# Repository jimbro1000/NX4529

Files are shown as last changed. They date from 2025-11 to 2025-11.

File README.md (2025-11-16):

# MC14529 Replacement #

This repository contains the design for a CPLD based
replacement for the long obsolete MC14529 analog
multiplexer. The design is intended only to act as a
substitute in the Dragon 32/64 computers.

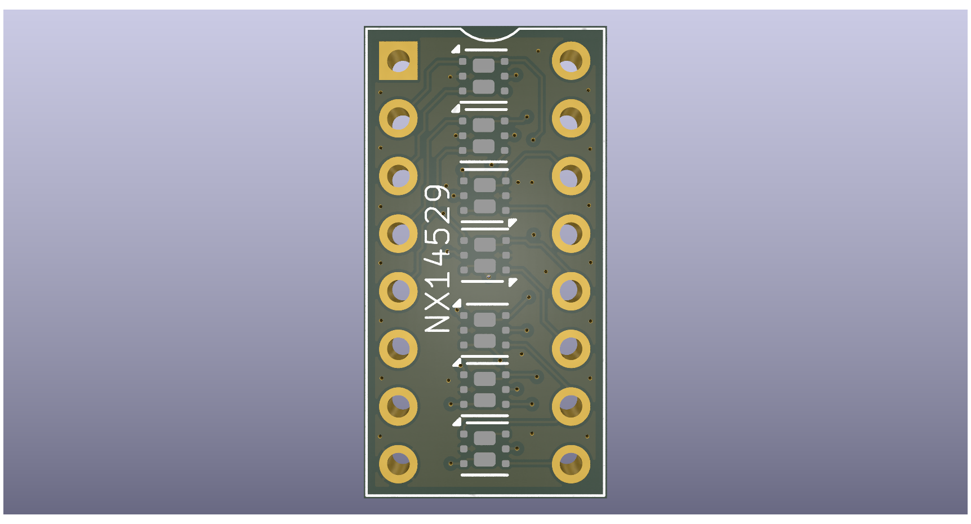
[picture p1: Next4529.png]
render of pcb


## Limitations ##

The original MC14529 can act a 8:1 multiplexer which ties
the two output pins together. It can also place the two
output pins in a high impedance state.

In both cases these configurations are limited in this 
design to suit the specific use-case for the Dragon.

1. The high impedance state is not implemented
2. The two output pins are only correct when the X
inputs are selected, if the Y inputs are selected the 
result will still be two independant outputs

## Design ##

The design is based around the Renesas SLG46824 CPLD.
This is a 3mm x 2mm device (about the size of a 1/4W
leaded resistor). The CPLD reproduces the truth table
of the original device.

The actual multiplexing is performed by an array of
LS74LVC1G3157 analog SPDT switches. These are available
in very small packages allowing seven of them to be
fitted in the available space.

The board design must retain the footprint of a DIP-16
device and provides the most significant design constraint.

## License ##

This project is licensed under creative commons CC-BY-SA 4.0

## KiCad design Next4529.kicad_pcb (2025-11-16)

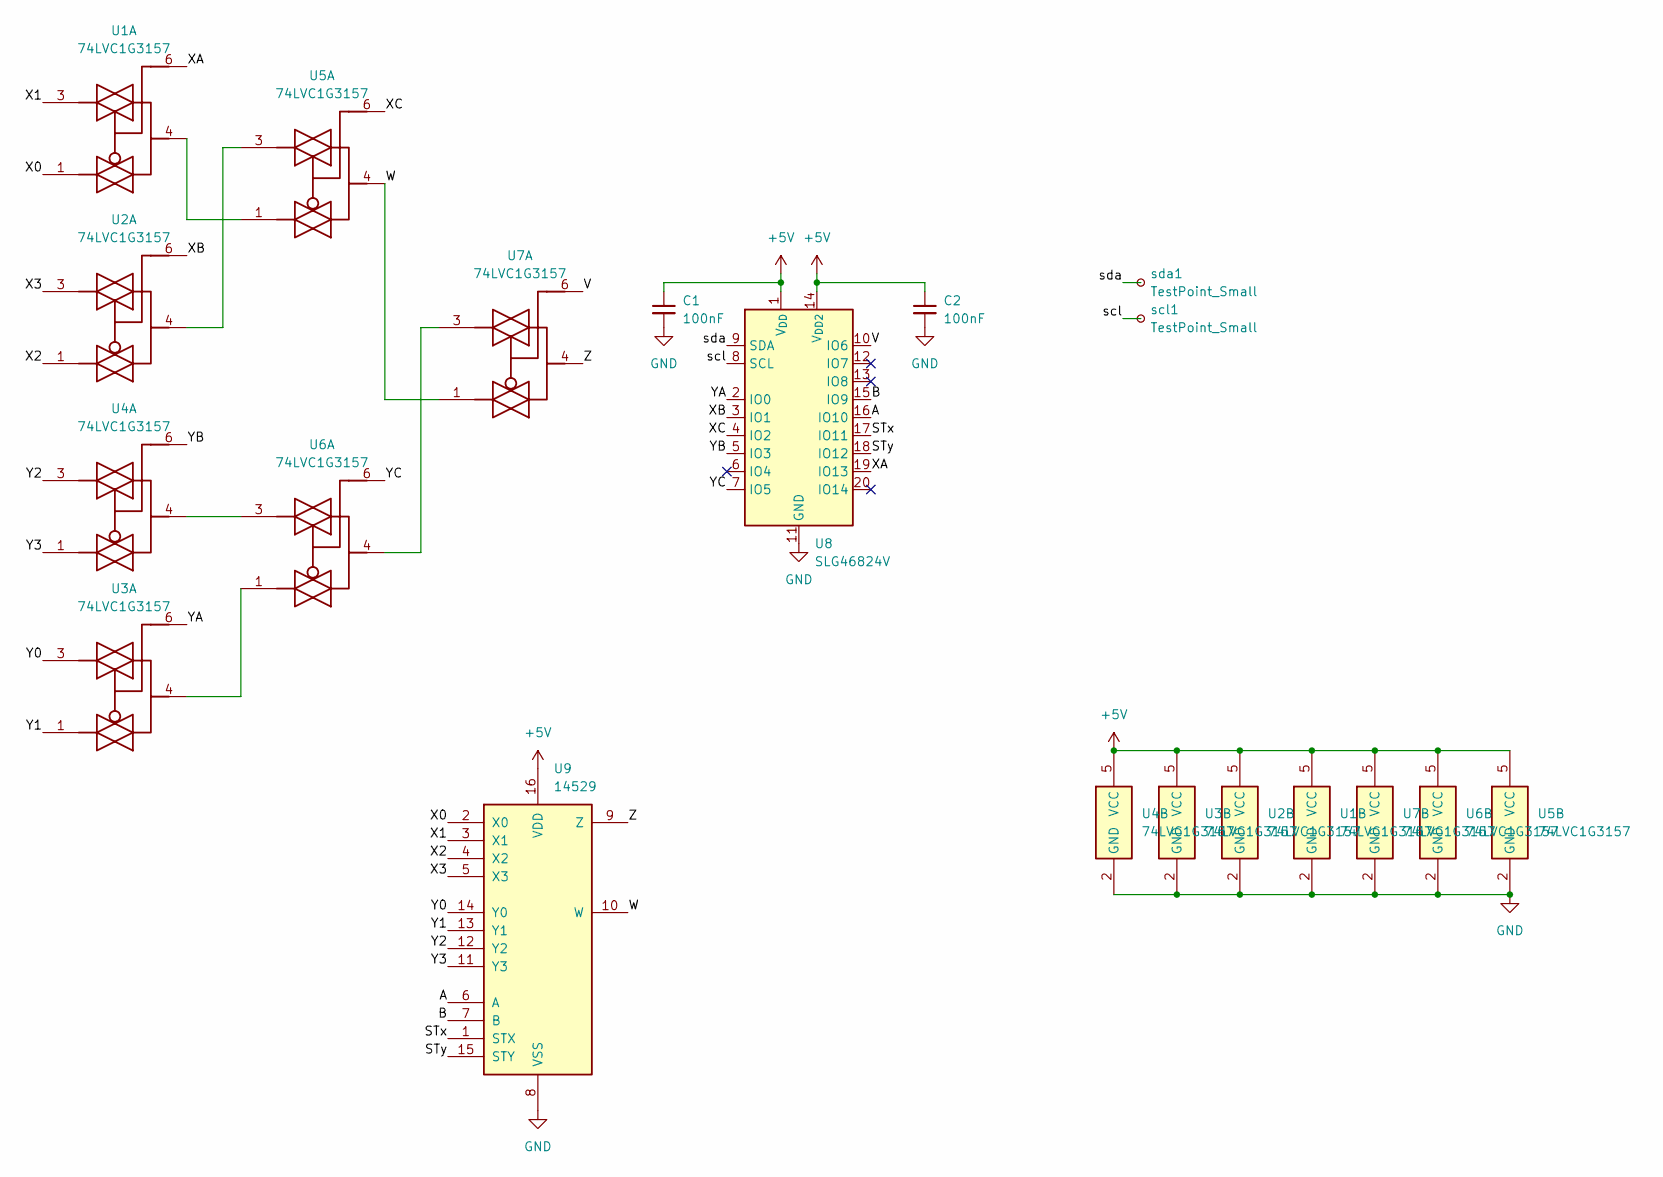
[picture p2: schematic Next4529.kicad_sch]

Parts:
C1, C2: 100nF; C_0402_1005Metric; DigiKey 1276-CL05B104KP5VPNCCT-ND
U1, U2, U3, U4, U5, U6, U7: 74LVC1G3157; Vishay_PowerPAK_SC70-6L_Dual; DigiKey 296-14909-1-ND
U8: SLG46824V; Renesas_UQFN-20_2x3mm_P0.4mm_LayoutBorder4x6y; DigiKey 1695-SLG46824VCT-ND
U9: 14529; DIP-16_board
scl1: TestPoint_Small; TestPoint_Pad_D1.0mm
sda1: TestPoint_Small; TestPoint_Pad_D1.0mm

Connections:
+5V: C1.1, C2.1, U1.5 (VCC), U2.5 (VCC), U3.5 (VCC), U4.5 (VCC), U5.5 (VCC), U6.5 (VCC), U7.5 (VCC), U8.1 (V_{DD}), U8.14 (V_{DD2}), U9.16 (VDD)
/A: U8.16 (IO10), U9.6 (A)
/B: U8.15 (IO9), U9.7 (B)
/STx: U8.17 (IO11), U9.1 (STX)
/STy: U8.18 (IO12), U9.15 (STY)
/V: U7.6, U8.10 (IO6)
/W: U5.4, U7.1, U9.10 (W)
/X0: U1.1, U9.2 (X0)
/X1: U1.3, U9.3 (X1)
/X2: U2.1, U9.4 (X2)
/X3: U2.3, U9.5 (X3)
/XA: U1.6, U8.19 (IO13)
/XB: U2.6, U8.3 (IO1)
/XC: U5.6, U8.4 (IO2)
/Y0: U3.3, U9.14 (Y0)
/Y1: U3.1, U9.13 (Y1)
/Y2: U4.3, U9.12 (Y2)
/Y3: U4.1, U9.11 (Y3)
/YA: U3.6, U8.2 (IO0)
/YB: U4.6, U8.5 (IO3)
/YC: U6.6, U8.7 (IO5)
/Z: U7.4, U9.9 (Z)
/scl: U8.8 (SCL), scl1.1
/sda: U8.9 (SDA), sda1.1
GND: C1.2, C2.2, U1.2 (GND), U2.2 (GND), U3.2 (GND), U4.2 (GND), U5.2 (GND), U6.2 (GND), U7.2 (GND), U8.11 (GND), U9.8 (VSS)
unnamed: U1.4, U5.1
unnamed: U2.4, U5.3
unnamed: U3.4, U6.1
unnamed: U4.4, U6.3
unnamed: U6.4, U7.3

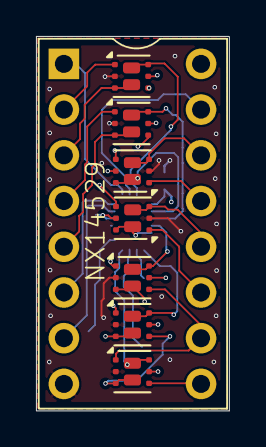
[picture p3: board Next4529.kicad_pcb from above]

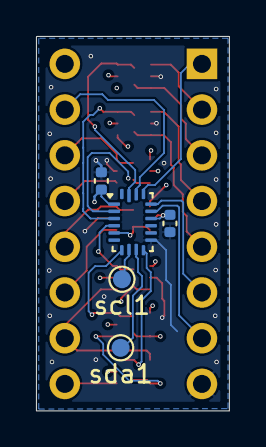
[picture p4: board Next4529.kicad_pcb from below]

Board: 4 copper layers, 10.7 x 20.8 mm, 13 parts (5 on the bottom side), 30 nets.
